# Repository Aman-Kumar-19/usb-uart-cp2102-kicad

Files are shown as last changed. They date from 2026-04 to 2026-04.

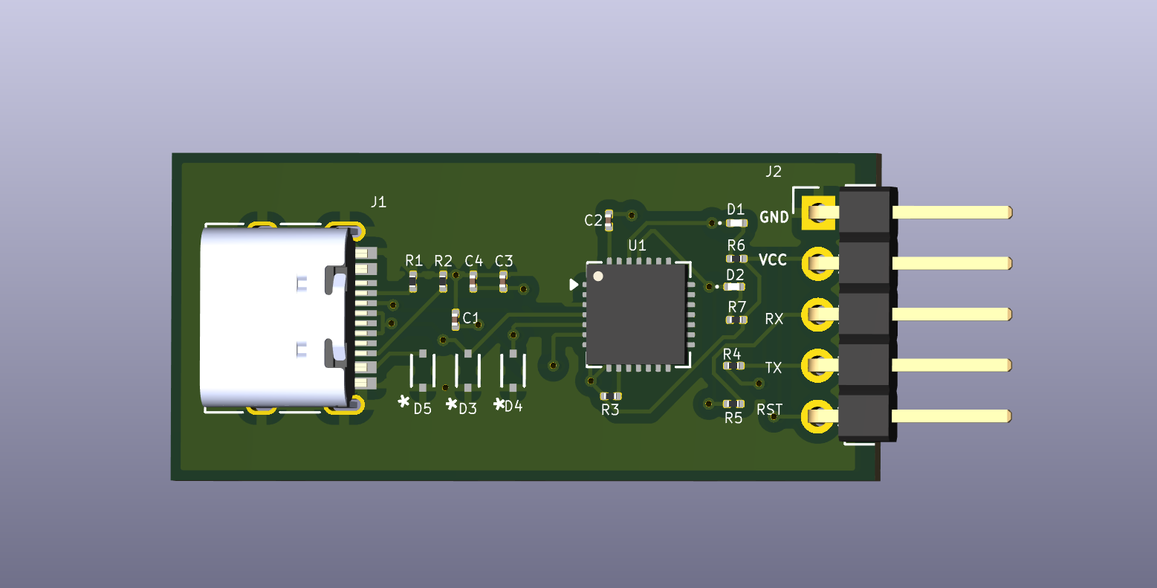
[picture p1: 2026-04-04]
docs/3d_view_front.png

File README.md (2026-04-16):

# 🔌 USB to UART Converter (CP2102)

A professionally designed **USB to UART (TTL) converter PCB** developed using KiCad, based on the CP2102 USB bridge IC. This project demonstrates industry-standard hardware design practices for reliable USB communication and embedded system interfacing.

---

## 🚀 Features

* USB to TTL UART conversion (3.3V logic)
* CP2102 USB-UART bridge (no external crystal required)
* TX/RX activity indication using LEDs
* Compact 2-layer PCB design
* Optimized for embedded debugging and programming

---

## 🧠 Design Methodology

The design is implemented following professional embedded hardware guidelines:

* **USB Signal Integrity**

  * Differential pair routing for D+ and D−
  * Short and matched trace lengths

* **Power Integrity**

  * Proper decoupling capacitors near IC power pins
  * Stable VBUS-based power design

* **Component Optimization**

  * Reduced BOM using CP2102 internal oscillator
  * Minimal and efficient external circuitry

* **Layout Considerations**

  * Functional block-based component placement
  * Ground plane for noise reduction

---

## 📸 Schematic


---

## 🧾 PCB Layout



---

## 🧊 3D View


-----



---

## 📦 Bill of Materials (BOM)

Available in `/BOM/bom.csv`

---

## 🛠️ Tools Used

* KiCad (Schematic + PCB Design)
* CP2102 Datasheet

---

## 🎯 Applications

* Embedded system debugging
* Microcontroller programming
* UART-based communication interfaces

---

## 📌 Key Learning Outcomes

* USB interface design fundamentals
* Differential signal routing
* Power integrity in PCB design
* Practical hardware implementation using KiCad

---

## 👨‍💻 Author

Aman Kumar

---

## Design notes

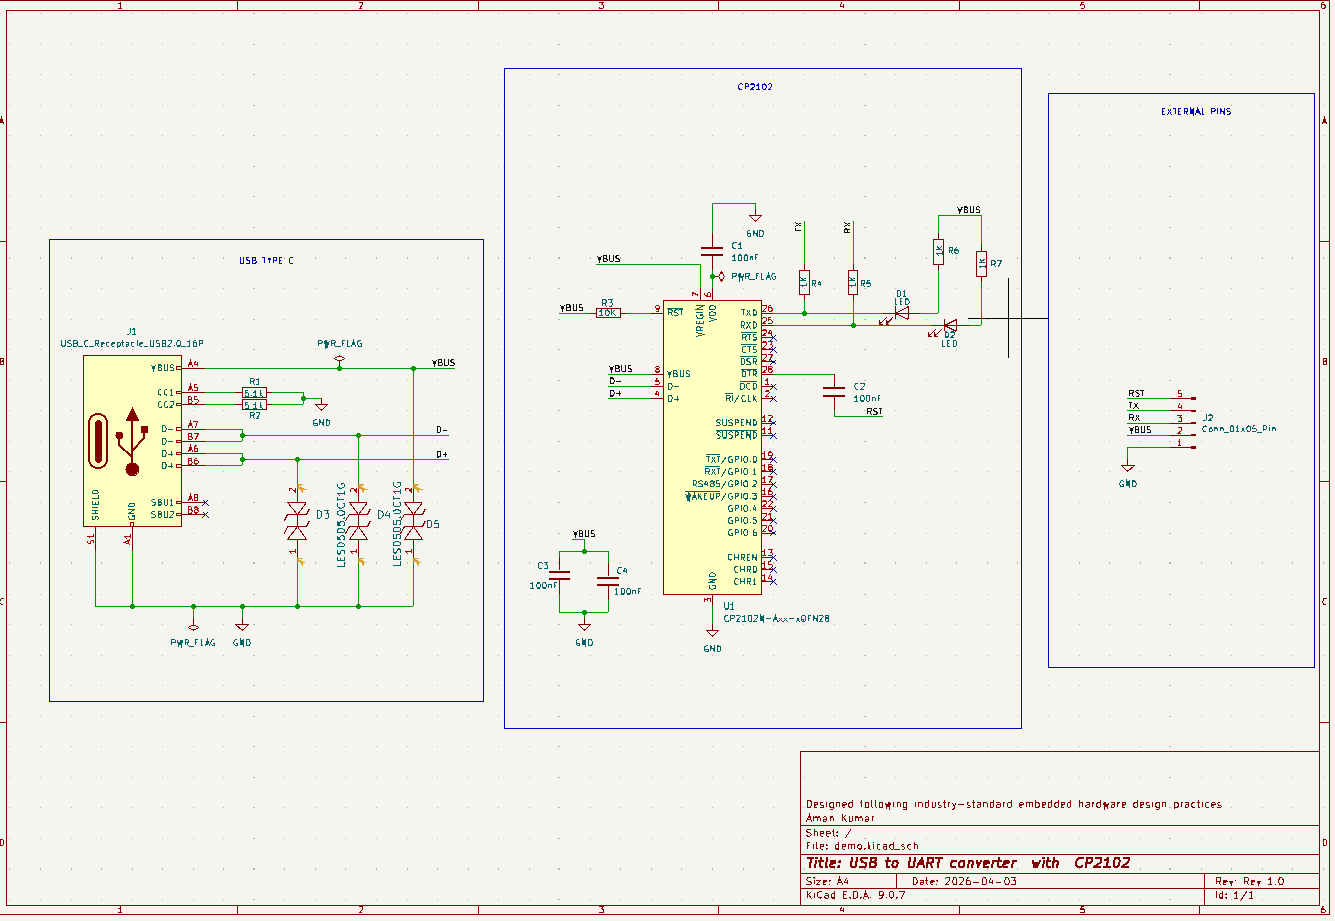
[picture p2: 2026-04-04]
docs/schematic.png

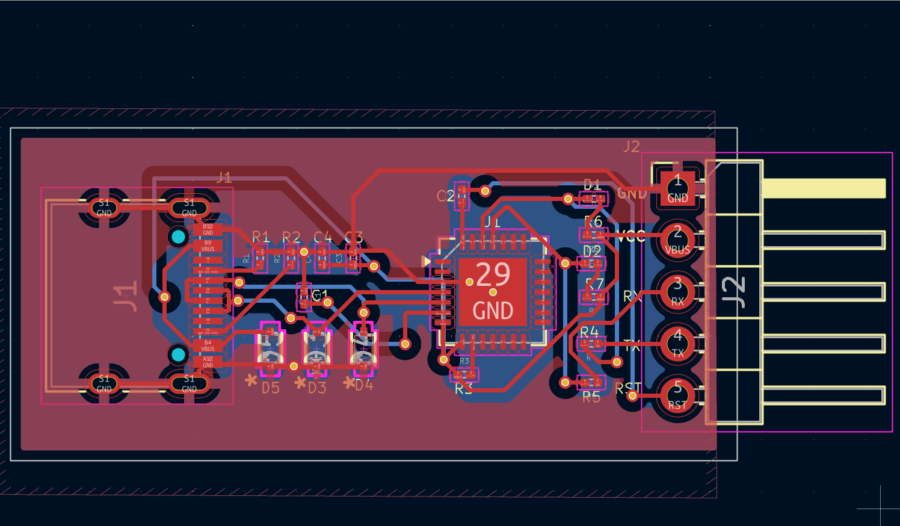
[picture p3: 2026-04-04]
docs/pcb.png

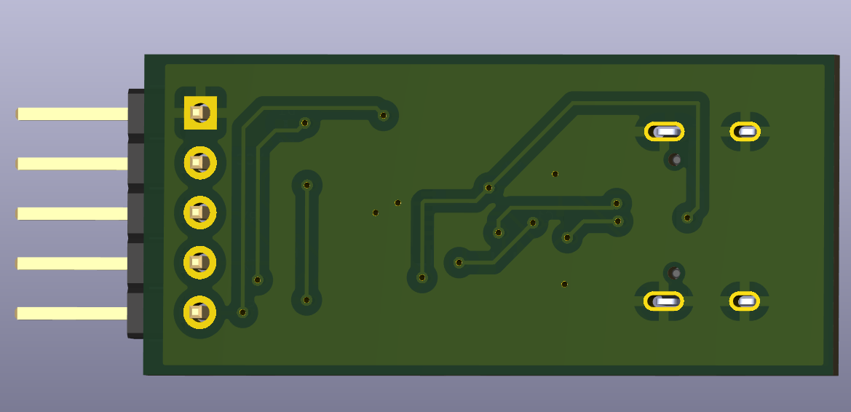
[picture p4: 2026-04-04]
docs/3d_view_back.png

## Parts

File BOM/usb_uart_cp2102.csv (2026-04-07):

Reference | "Qty" | "Value" | "DNP" | "Exclude from BOM" | "Exclude from Board" | "Footprint" | "Datasheet"
C1,C2,C3,C4 | "4" | "100nF" | "" | "" | "" | "Capacitor_SMD:C_0201_0603Metric" | "~"
D1,D2 | "2" | "LED" | "" | "" | "" | "LED_SMD:LED_0201_0603Metric" | "~"
D3,D4,D5 | "3" | "LESD5D5.0CT1G" | "" | "" | "" | "LESD5D5-0CT1G:CR_5.0CT1G_UMW" | "LESD5D5.0CT1G"
J1 | "1" | "USB_C_Receptacle_USB2.0_16P" | "" | "" | "" | "Connector_USB:USB_C_Receptacle_HRO_TYPE-C-31-M-12" | "https://www.usb.org/sites/default/files/documents/usb_type-c.zip"
J2 | "1" | "Conn_01x05_Pin" | "" | "" | "" | "Connector_PinHeader_2.54mm:PinHeader_1x05_P2.54mm_Horizontal" | "~"
R1,R2 | "2" | "5.1k" | "" | "" | "" | "Resistor_SMD:R_0201_0603Metric" | "~"
R3 | "1" | "10K" | "" | "" | "" | "Resistor_SMD:R_0201_0603Metric" | "~"
R4,R5,R6,R7 | "4" | "1K" | "" | "" | "" | "Resistor_SMD:R_0201_0603Metric" | "~"
U1 | "1" | "CP2102N-Axx-xQFN28" | "" | "" | "" | "Package_DFN_QFN:QFN-28-1EP_5x5mm_P0.5mm_EP3.35x3.35mm" | "https://www.silabs.com/documents/public/data-sheets/cp2102n-datasheet.pdf"

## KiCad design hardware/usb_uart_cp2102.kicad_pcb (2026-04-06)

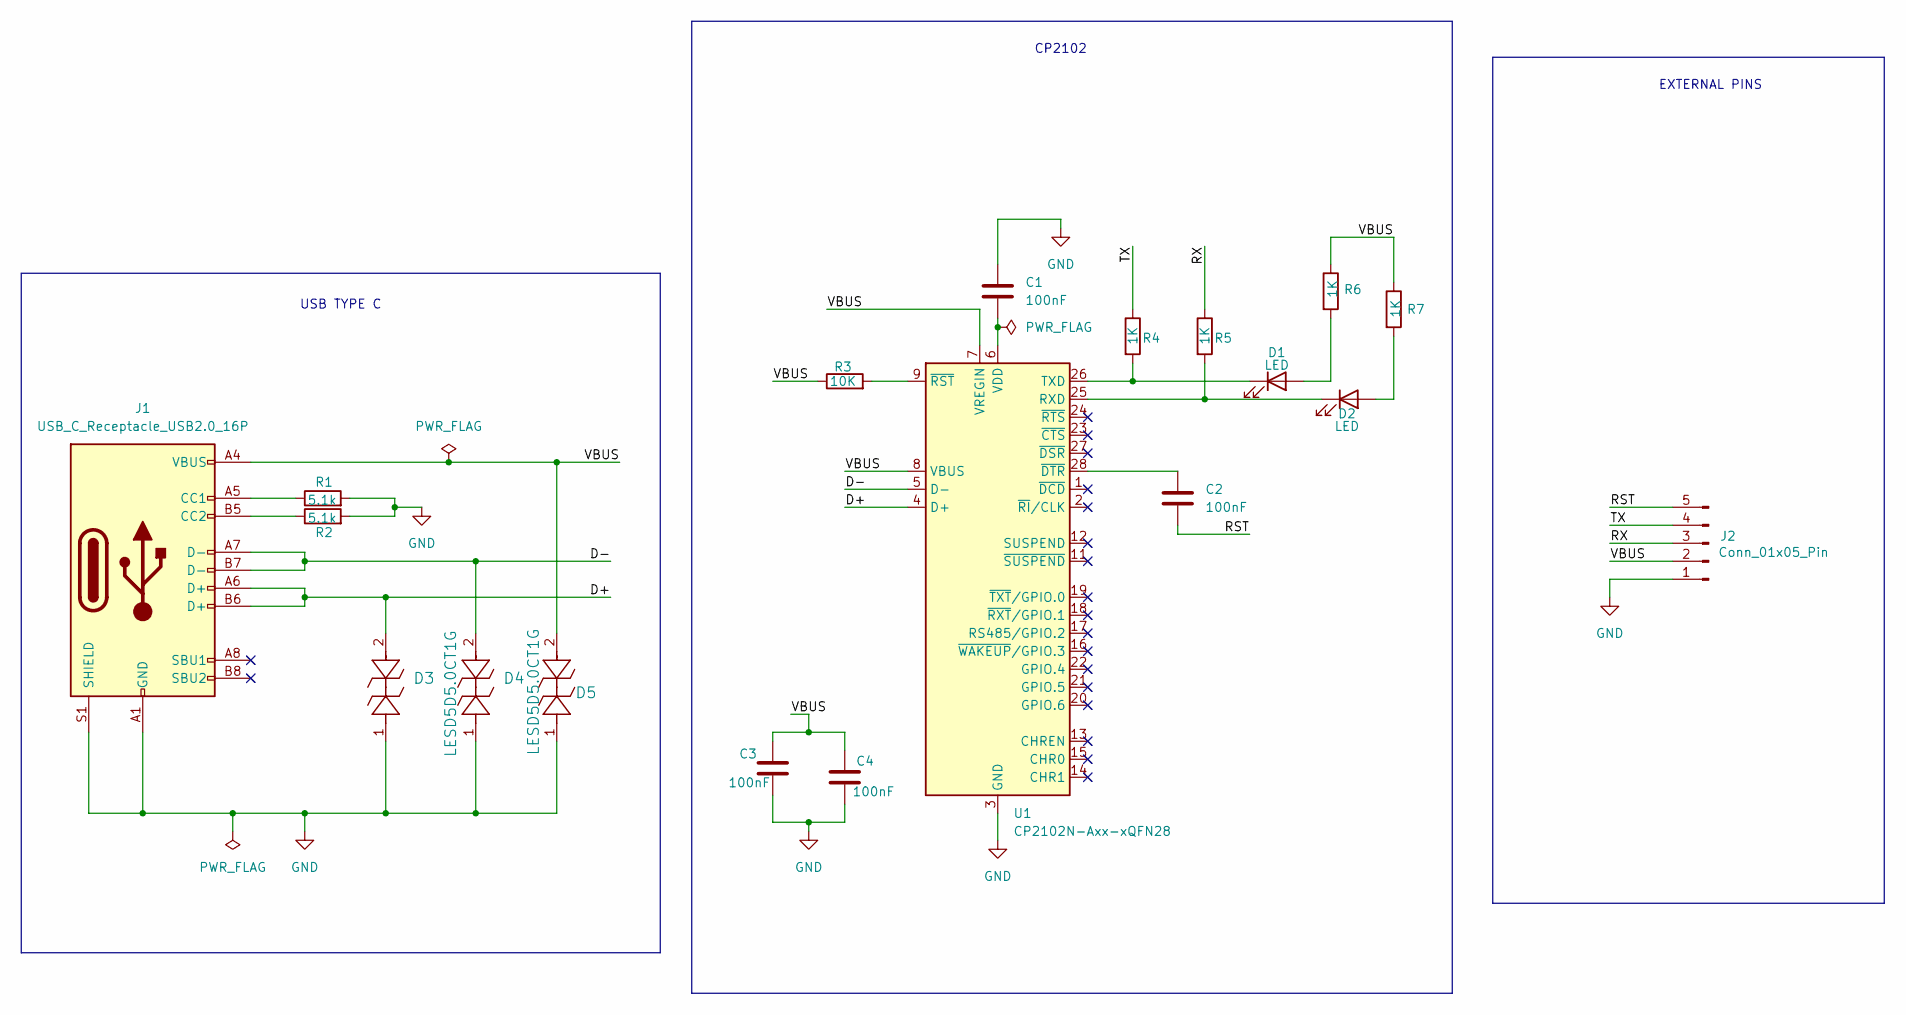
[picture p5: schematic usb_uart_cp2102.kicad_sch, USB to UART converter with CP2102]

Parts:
C1, C2, C3, C4: 100nF; C_0201_0603Metric
D1, D2: LED; LED_0201_0603Metric
D3, D4, D5: LESD5D5.0CT1G; CR_5.0CT1G_UMW
J1: USB_C_Receptacle_USB2.0_16P; USB_C_Receptacle_HRO_TYPE-C-31-M-12
J2: Conn_01x05_Pin; PinHeader_1x05_P2.54mm_Horizontal
R1, R2: 5.1k; R_0201_0603Metric
R3: 10K; R_0201_0603Metric
R4, R5, R6, R7: 1K; R_0201_0603Metric
U1: CP2102N-Axx-xQFN28; QFN-28-1EP_5x5mm_P0.5mm_EP3.35x3.35mm

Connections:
/D+: D3.2, J1.A6 (D+), J1.B6 (D+), U1.4 (D+)
/D-: D4.2, J1.A7 (D-), J1.B7 (D-), U1.5 (D-)
/RST: C2.2, J2.5
/RX: J2.3, R5.1
/TX: J2.4, R4.1
/VBUS: C3.1, C4.1, D5.2, J1.A4 (VBUS), J1.A9 (VBUS), J1.B4 (VBUS), J1.B9 (VBUS), J2.2, R3.1, R6.1, R7.1, U1.7 (VREGIN), U1.8 (VBUS)
GND: C1.1, C3.2, C4.2, D3.1, D4.1, D5.1, J1.A1 (GND), J1.A12 (GND), J1.B1 (GND), J1.B12 (GND), J1.S1 (SHIELD), J2.1, R1.2, R2.2, U1.3 (GND), U1.29 (GND)
unnamed: D1.2 (A), R6.2
unnamed: D1.1 (K), R4.2, U1.26 (TXD)
unnamed: D2.2 (A), R7.2
unnamed: D2.1 (K), R5.2, U1.25 (RXD)
unnamed: J1.A5 (CC1), R1.1
unnamed: J1.B5 (CC2), R2.1
unnamed: C1.2, U1.6 (VDD)
unnamed: C2.1, U1.28 (~DTR)
unnamed: R3.2, U1.9 (~RST)

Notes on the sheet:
CP2102
USB TYPE C
EXTERNAL PINS

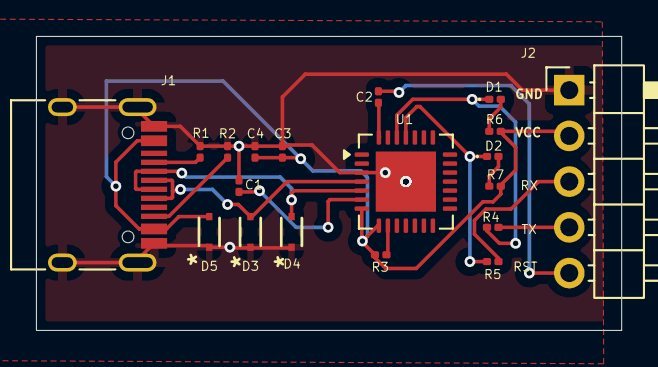
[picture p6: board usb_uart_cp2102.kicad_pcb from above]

Board: 2 copper layers, 32.5 x 16.3 mm, 19 parts (0 on the bottom side), 16 nets.

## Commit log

2026-04-04 Revise README for USB to UART Converter project
    Updated README to enhance project description and added detailed sections on features, design methodology, schematic, PCB layout, 3D view, BOM, tools used, applications, and key learning outcomes.
2026-04-16 Update PCB Layout and 3D View images in README
